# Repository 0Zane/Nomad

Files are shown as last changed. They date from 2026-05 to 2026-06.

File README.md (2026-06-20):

# Nomad

**Outdoor embedded device for exploration**






Nomad is a custom outdoor mobile device built around the **ESP32-S3**. It is designed for explorers, researchers, and outdoor enthusiasts who need reliable positioning, long-range communication, environmental awareness, and practical survival utilities in a compact rugged package.
I made this project entirely myself, the idea comes from my passion of making useful objects that help people in specific actions.

> **Project status:** Active development  
> **Last updated:** June 2026

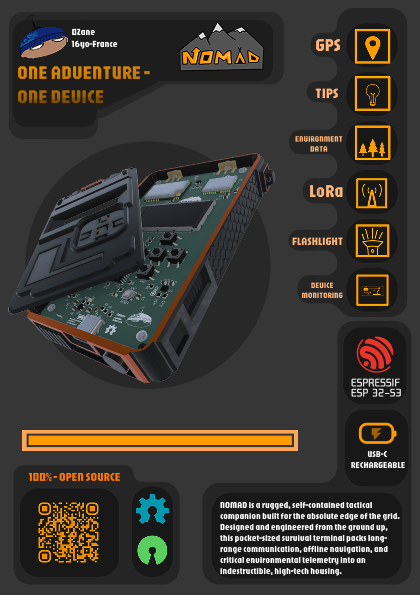
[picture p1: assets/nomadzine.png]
Nomad zine


## Documentation

| Resource | Description |
| --- | --- |
| [Nomad Zine](https://github.com/0Zane/Nomad/blob/341650ad904c9da342a7fef04f9b7398d65ead2c/assets/nomadzine.png) | Visual project zine and product-style overview |
| [Bill of Materials](https://github.com/0Zane/Nomad/blob/main/pcb/bom.csv) | Complete component list with quantities and specifications |
| [Main Schematic](https://github.com/0Zane/Nomad/blob/1c8a336e28e47b4648a542668c6f2eea3e4071de/pcb/nomad.svg) | Full board schematic |
| [Module Schematic](https://github.com/0Zane/Nomad/blob/1c8a336e28e47b4648a542668c6f2eea3e4071de/pcb/modules.svg) | Supporting module schematic |

## Table of Contents

- [Project Overview](#project-overview)
- [Key Features](#key-features)
- [Technical Architecture](#technical-architecture)
- [Hardware Design](#hardware-design)
- [Bill of Materials](#bill-of-materials)
- [Firmware](#firmware)
- [Project Structure](#project-structure)
- [License](#license)

## Project Overview

Nomad combines navigation, messaging, sensing, power management, and a custom interface into one portable embedded system.

The device is built for field use, with an emphasis on:

- Knowing where you are through GPS positioning and waypoint tracking.
- Staying connected through long-range LoRa messaging.
- Understanding local conditions through environmental sensing.
- Conserving energy through deep sleep and power-aware firmware.
- Providing simple, fast interaction through buttons and a menu-driven UI.
- Accessing to useful survival tips 
## Key Features

| Feature | What it enables |
| --- | --- |
| **GPS navigation** | Real-time position, coordinates, and waypoint-oriented navigation |
| **LoRa communication** | Long-range SOS alerts, coordinate sharing, and lightweight messages |
| **Environmental monitoring** | Temperature, pressure, and altitude-related readings |
| **Menu-driven UI** | Multi-level navigation built around a clear state-machine structure |
| **Survival tips** | Practical outdoor guidance available directly on the device |
| **Battery optimization** | Deep sleep and intelligent power-management behavior |
| **Custom PCB** | Purpose-built hardware layout for the full Nomad system |
| **Rugged enclosure** | 3D-designed case for portable outdoor use |

## Technical Architecture

### Core Components

| Component | Specification | Interface | Purpose |
| --- | --- | --- | --- |
| **MCU** | ESP32-S3-WROOM-1U | GPIO, UART, SPI, I2C | Main processor running C++ firmware with PlatformIO and Arduino |
| **Display** | 1.9 in IPS ST7789 display panel via FPC | SPI | Smooth UI rendering with menu/submenu screens and PWM brightness control |
| **GPS** | u-blox NEO-M8M | UART | High-precision localization using the TinyGPS++ library |
| **LoRa** | Ebyte E220-900T22S | UART | Long-range messaging for SOS, coordinate sharing, and text packets |
| **Environmental sensor** | BME280 | I2C | Temperature and atmospheric pressure sensing |
| **Input** | 5 buttons with PCF8574T GPIO expander | I2C | Robust button handling with interrupt support |
| **Fuel gauge** | MAX17048G_T10 | I2C | Battery voltage and state-of-charge monitoring |
| **Charger IC** | MCP73831-2-OT | Power management | Li-Po battery charging management |
| **Buck-boost converter** | TPS63060 | Power management | Stable regulated power delivery |
| **Flashlight** | LED | GPIO pin 1 | Controlled illumination for field use |
| **Power source** | Protected Li-ion battery | Power | Main battery with integrated protection circuit |

### Development Stack

| Layer | Tooling |
| --- | --- |
| **Language** | C++ |
| **Framework** | Arduino |
| **Build system** | PlatformIO |
| **IDE** | VS Code with the PlatformIO extension |
| **Primary firmware target** | ESP32-S3 |

## Hardware Design

### Main Schematic

Nomad main schematic

### Module Schematic

Nomad module schematic

### PCB Layout

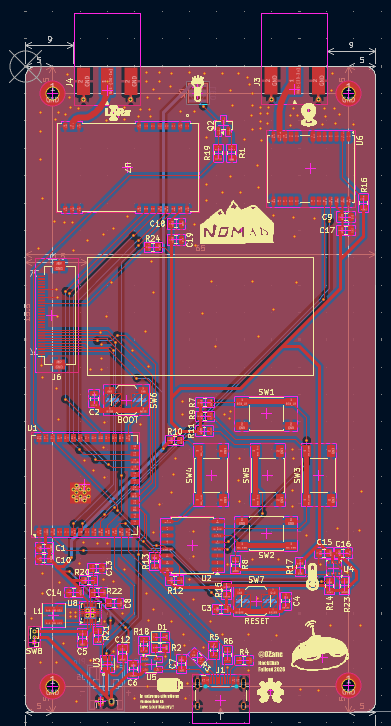
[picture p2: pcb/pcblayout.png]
Nomad PCB layout


### 3D Case

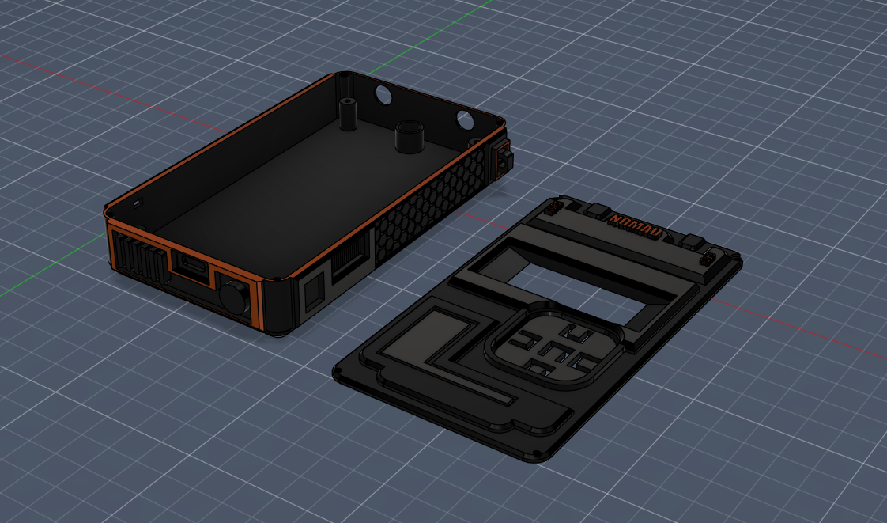
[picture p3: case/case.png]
Nomad case


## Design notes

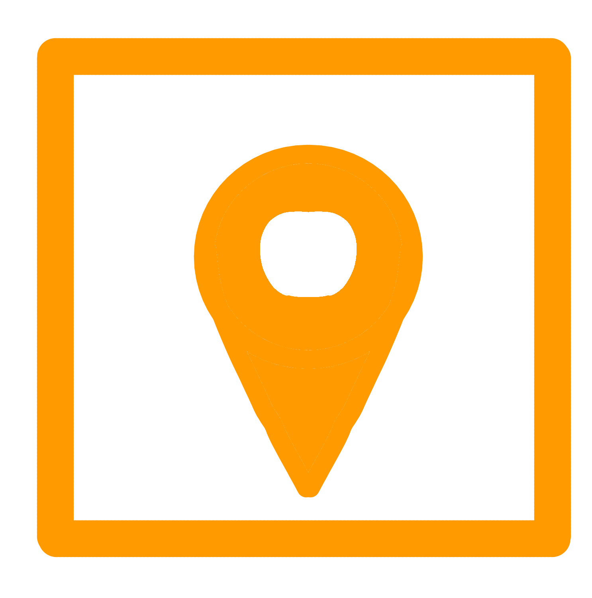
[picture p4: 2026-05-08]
assets/gps.png

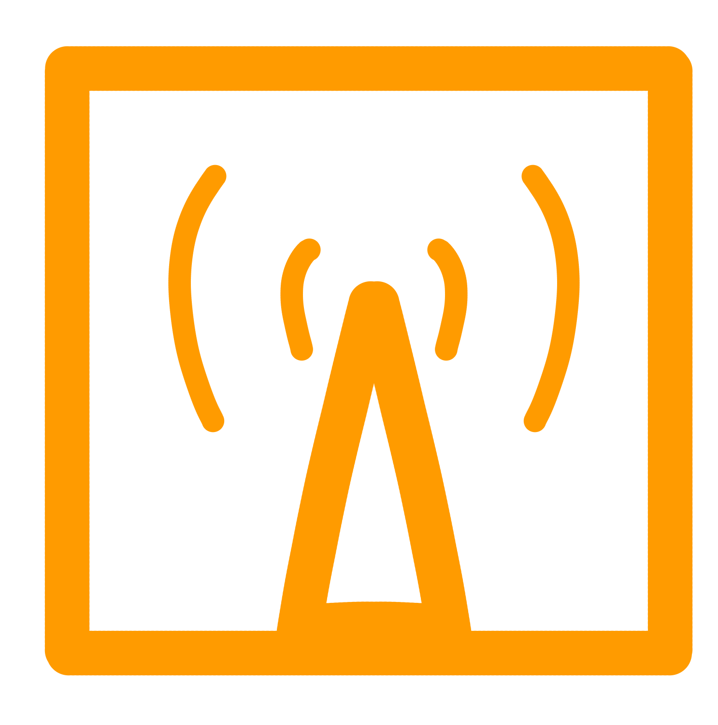
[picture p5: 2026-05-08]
assets/lora.png

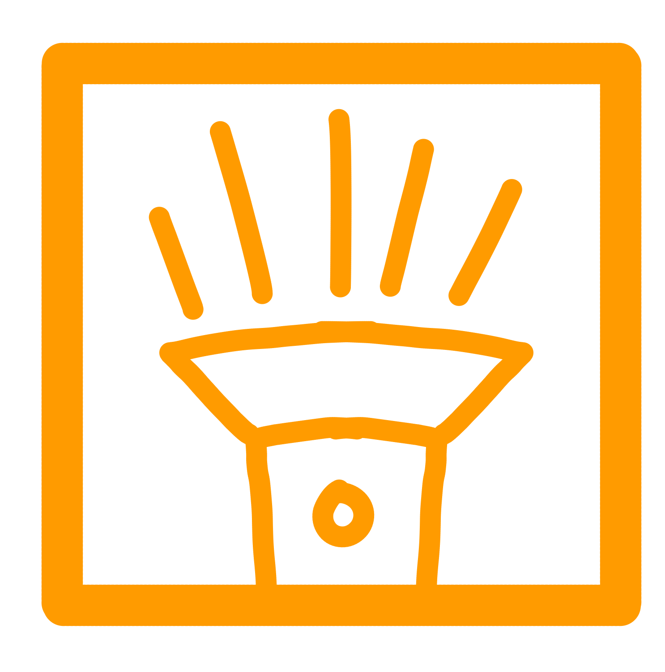
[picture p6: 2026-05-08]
assets/flashlight.png

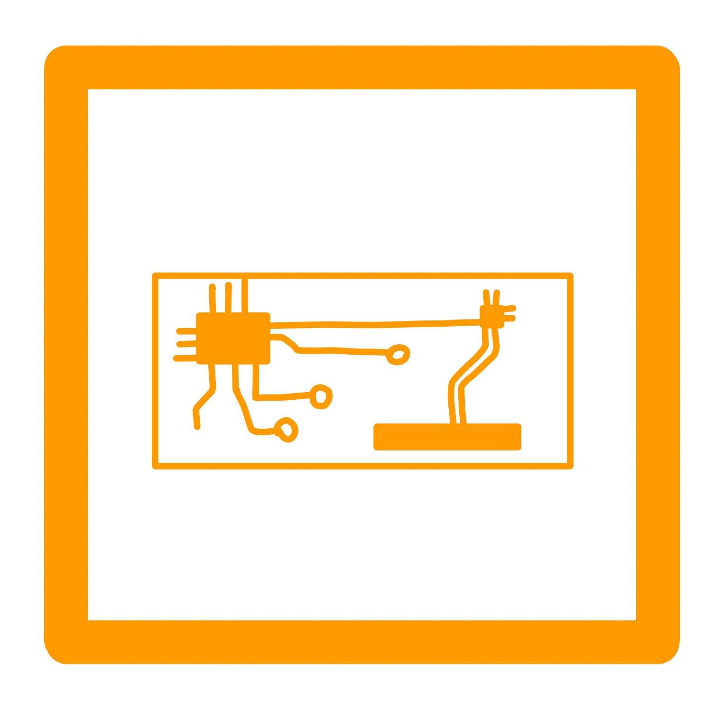
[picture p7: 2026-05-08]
assets/device.png

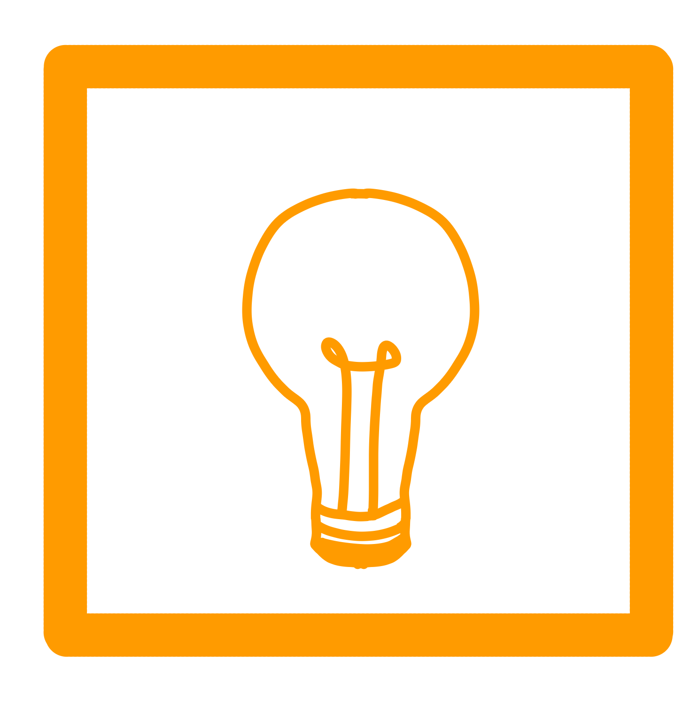
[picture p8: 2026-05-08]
assets/tips.png

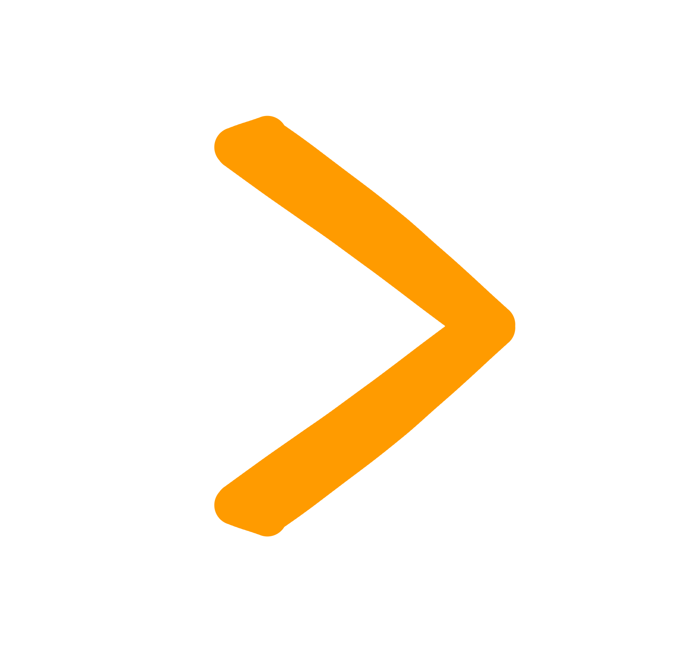
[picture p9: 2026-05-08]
assets/rightarrow.png

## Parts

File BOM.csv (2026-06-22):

Reference | Qty (used) | Value | Footprint | Datasheet | "Ext.price" | "buy link"
C1,C2,C3,C4,C8,C9,C12,C15,C16,C18 | 10 | 0.1uF | Capacitor_SMD:C_0805_2012Metric | "" | $0.25 | "https://www.lcsc.com/product-detail/C1711.html"
C5,C10,C11,C14,C20 | 5 | 22uF | Capacitor_SMD:C_0805_2012Metric | "" | "$0.33" | "https://www.lcsc.com/product-detail/C602037.html"
C6,C7 | 2 | 4.7uF | Capacitor_SMD:C_0805_2012Metric |  | "$0.28" | "https://www.lcsc.com/product-detail/C98192.html"
C13 | 1 | 10pF | Capacitor_SMD:C_0805_2012Metric |  | $0.34 | "https://www.lcsc.com/product-detail/C15850.html"
C17,C19 | 2 | 10uF | Capacitor_SMD:C_0805_2012Metric |  | $0.59 | https://www.lcsc.com/product-detail/C15850.html
D1 | 1 | LED | LED_SMD:LED_0805_2012Metric |  | "1.08€" | "https://fr.aliexpress.com/item/1005006781648580.html"
D2 | 1 | LED | LED_SMD:LED_Cree-XP-G |  | "0.90€" | "https://www.digikey.fr/fr/products/detail/cree-led/XPEBTT-01-0000-00V80/5303634"
J1 | 1 | USB_C_Receptacle_USB2.0_16P | Connector_USB:USB_C_Receptacle_HCTL_HC-TYPE-C-16P-01A | https://www.usb.org/sites/default/files/documents/usb_type-c.zip | "8.99€" | https://www.amazon.fr/dp/B0CJF7KPV8?
J3,J4 | 2 | Conn_Coaxial | Connector_Coaxial:SMA_Molex_73251-1153_EdgeMount_Horizontal |  | "0 | 99€" | "https://fr.aliexpress.com/item/1005009943868026.html"
J5 | 1 | Conn_01x02_Pin | Connector_JST:JST_PH_S2B-PH-K_1x02_P2.00mm_Horizontal |  | "0 | 11 $" | "https://www.digikey.fr/en/products/detail/jst-sales-america-inc/S2B-PH-K-S/926626"
J6 | 1 | Conn_01x30 | Connector_FFC-FPC:Hirose_FH12-30S-0.5SH_1x30-1MP_P0.50mm_Horizontal |  | "2 | 11 $" | "https://www.digikey.fr/en/products/detail/hirose-electric-co-ltd/FH12-30S-0-5SH-55/1000799"
L1 | 1 | 1uH | Inductor_SMD:L_Coilcraft_XxL4020 |  | 1.63€ | https://fr.aliexpress.com/item/1005007108638684.html
Q2 | 1 | 2N7002 | Package_TO_SOT_SMD:SOT-23 | https://www.onsemi.com/pub/Collateral/NDS7002A-D.PDF | "$0.30" | "https://www.lcsc.com/product-detail/C916396.html"
R1 | 1 | 1.5k | Resistor_SMD:R_0805_2012Metric |  | "$0.13" | "https://www.lcsc.com/product-detail/C114555.html"
R2 | 1 | 2K | Resistor_SMD:R_0805_2012Metric |  | "$0.10" | "https://www.lcsc.com/product-detail/C2907248.html"
R3,R4 | 2 | 5.1k | Resistor_SMD:R_0805_2012Metric |  | $0.12 | "https://www.lcsc.com/product-detail/C27834.html"
R5,R6 | 2 | 22R | Resistor_SMD:R_0805_2012Metric |  | $0.10 | "https://www.lcsc.com/product-detail/C2907244.html"
R7,R8,R9,R10,R11,R15,R16 | 7 | 10k | Resistor_SMD:R_0805_2012Metric |  | "$0.10" | "https://www.lcsc.com/product-detail/C2907219.html"
R12,R13,R14,R17 | 4 | 4.7k | Resistor_SMD:R_0805_2012Metric |  | $0.09 | "https://www.lcsc.com/product-detail/C2907326.html"
R18 | 1 | 470R | Resistor_SMD:R_0805_2012Metric |  | "$0.11" | "https://www.lcsc.com/product-detail/C2907267.html"
R19 | 1 | 100R | Resistor_SMD:R_0805_2012Metric |  | "$0.34" | "https://www.lcsc.com/product-detail/C844936.html"
R20 | 1 | 560k | Resistor_SMD:R_0805_2012Metric |  | "$0.09" | "https://www.lcsc.com/product-detail/C2933556.html"
R21 | 1 | 1M | Resistor_SMD:R_0805_2012Metric |  | "4.19€" | "https://fr.aliexpress.com/item/1005005580397963.html"
R22 | 1 | 100k | Resistor_SMD:R_0805_2012Metric |  | "$0.12" | "https://www.lcsc.com/product-detail/C149504.html"
R23 | 1 | 1K | Resistor_SMD:R_0805_2012Metric |  | "$0.10" | "https://www.lcsc.com/product-detail/C2907232.html"
R24 | 1 | 5.1R | Resistor_SMD:R_0805_2012Metric |  | "4.19€" | "https://fr.aliexpress.com/item/1005005580397963.html"
SW1,SW2,SW3,SW4,SW5 | 5 |  | Button_Switch_SMD:SW_Push_1P1T_NO_E-Switch_TL3301NxxxxxG |  | "2 | 49€" | "https://fr.aliexpress.com/item/1005006950491591.html"
SW6,SW7 | 2 | SW_Push | Button_Switch_SMD:SW_SPST_SKQG_WithStem |  | "5.89€" | "https://fr.aliexpress.com/item/1005008865429963.html"
SW8 | 1 | SW_SPDT | Connector_PinHeader_1.00mm:PinHeader_1x03_P1.00mm_Vertical |  | "4 | 87€" | "https://fr.aliexpress.com/item/1005007162182882.html"
U1 | 1 | ESP32-S3-WROOM-1 | RF_Module:ESP32-S3-WROOM-1U | https://www.espressif.com/sites/default/files/documentation/esp32-s3-wroom-1_wroom-1u_datasheet_en.pdf | "6 | 29€" | "https://fr.aliexpress.com/item/1005007001487286.html"
U2 | 1 | PCF8574T | Package_SO:SOIC-16W_7.5x10.3mm_P1.27mm | https://www.nxp.com/docs/en/data-sheet/PCF8574_PCF8574A.pdf | "$0.01" | https://www.lcsc.com/product-detail/C398075.html
U3 | 1 | MAX17048G_T10 | MAX17048G_T10:SON50P200X200X80-9N |  | "$1.58" | https://www.lcsc.com/product-detail/C2682616.html
U4 | 1 | BME280 | Package_LGA:Bosch_LGA-8_2.5x2.5mm_P0.65mm_ClockwisePinNumbering | https://www.bosch-sensortec.com/media/boschsensortec/downloads/datasheets/bst-bme280-ds002.pdf | "$3.86" | https://www.lcsc.com/product-detail/C92489.html
U5 | 1 | MCP73831-2-OT | Package_TO_SOT_SMD:SOT-23-5 | http://ww1.microchip.com/downloads/en/DeviceDoc/20001984g.pdf | "$0.59" | https://www.lcsc.com/product-detail/C424093.html
U6 | 1 | NEO-M8M | RF_GPS:ublox_NEO | https://content.u-blox.com/sites/default/files/NEO-M8-FW3_DataSheet_UBX-15031086.pdf | "$18.41" | "https://www.lcsc.com/product-detail/C5119406.html"
U7 | 1 | E220-900T22S | E220-900T22S_BYT | E220-900T22S | "$3.67" | "https://www.lcsc.com/product-detail/C970285.html"
U8 | 1 | TPS63060 | Package_SON:Texas_S-PWSON-N10_ThermalVias | http://www.ti.com/lit/ds/symlink/tps63060.pdf | "$1.08" | "https://www.lcsc.com/product-detail/C48567.html"
PCB | 5 | 2 Layer, 1.6mm | " default High-spec Options on JLCPCB" | "" | "$7.40" | "https://cart.jlcpcb.com/"
PCB shipping | "1" | "6-9 buisness days" | "EuroPacket" | "" | "$8.50" | "https://cart.jlcpcb.com/"
screen | "1" | "Display panel" | "SPI 1.9 IPS TFT LCD Display Panel 170x320 ST7789" | "https://www.buydisplay.com/download/manual/ER-TFT019-1_Datasheet.pdf" | "$6.39" | "https://www.buydisplay.com/full-viewing-angle-spi-1-9-inch-ips-tft-lcd-display-panel-170x320-st7789"
TOTAL PRICE | "" |  |  |  | 57.20$ + 41.51€ | THE PRICE IS NOT FOR 1 NOMAD DEVICE, MOST OF THE COMPONENTS ARE IN KITS

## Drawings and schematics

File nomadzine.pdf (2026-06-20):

# ONE ADVENTURE -

# ONE DEVICE

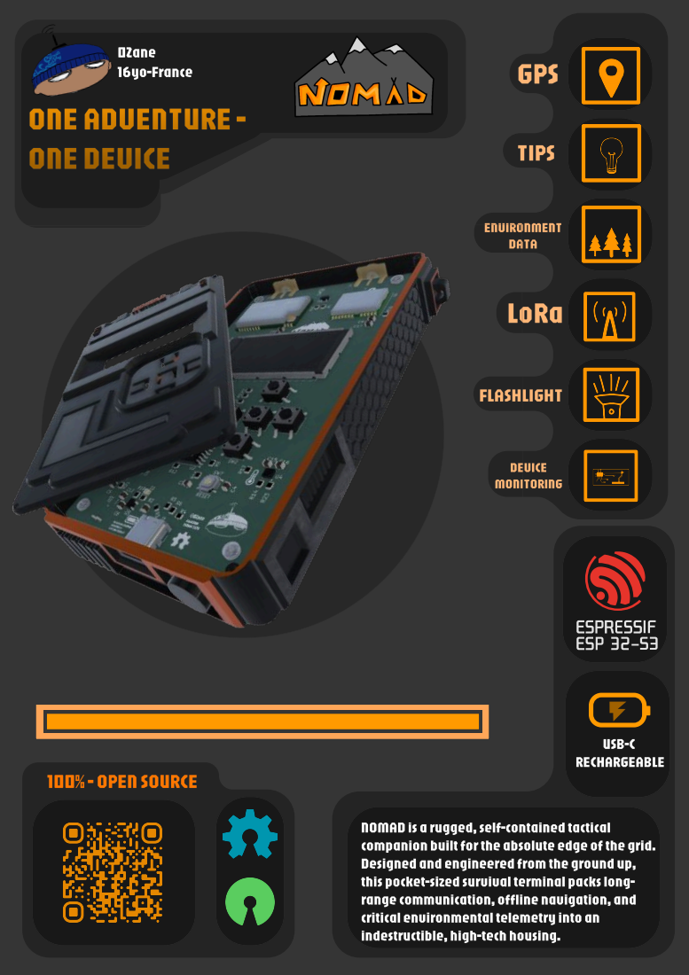
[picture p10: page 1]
0Zane; 16yo-France; GPS; TIPS; ENVIRONMENT; DATA; LoRa; FLASHLIGHT; DEVICE; MONITORING; 100% - OPEN SOURCE; USB-C; RECHARGEABLE

NOMAD is a rugged, self-contained tactical
companion built for the absolute edge of the grid.
Designed and engineered from the ground up,
this pocket-sized survival terminal packs long-
range communication, offline navigation, and
critical environmental telemetry into an
indestructible, high-tech housing.

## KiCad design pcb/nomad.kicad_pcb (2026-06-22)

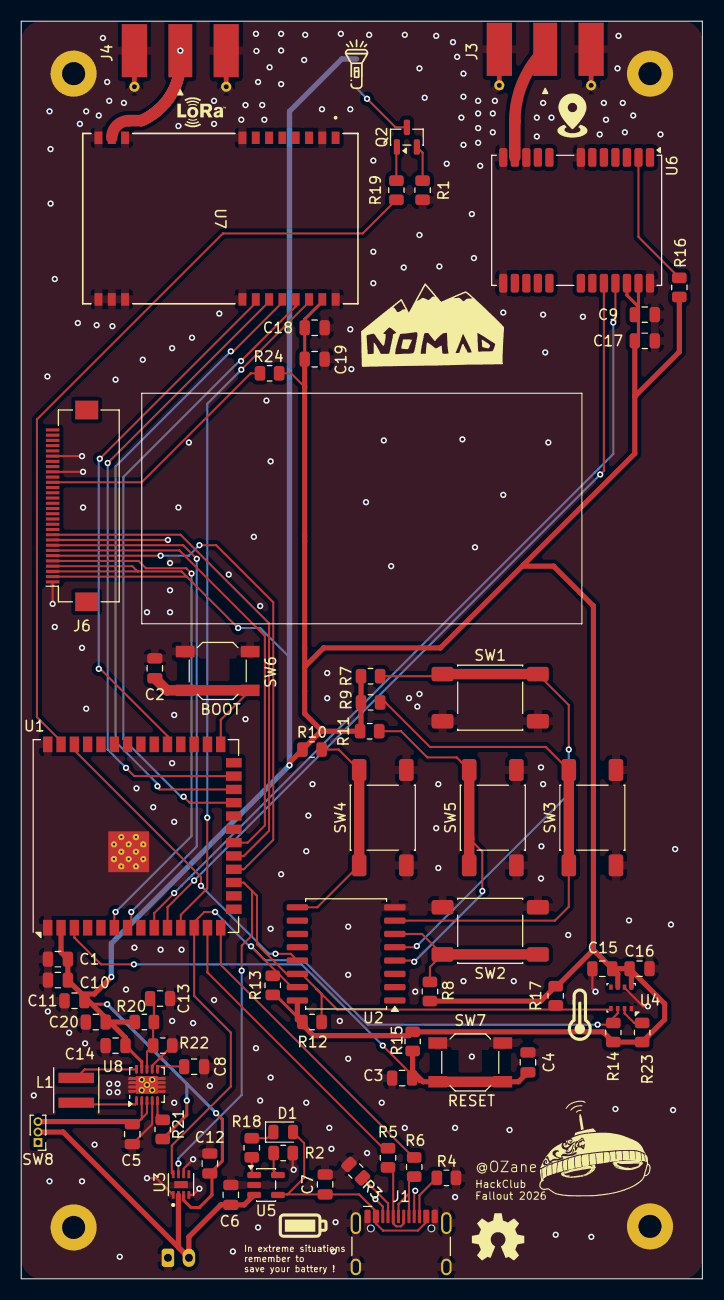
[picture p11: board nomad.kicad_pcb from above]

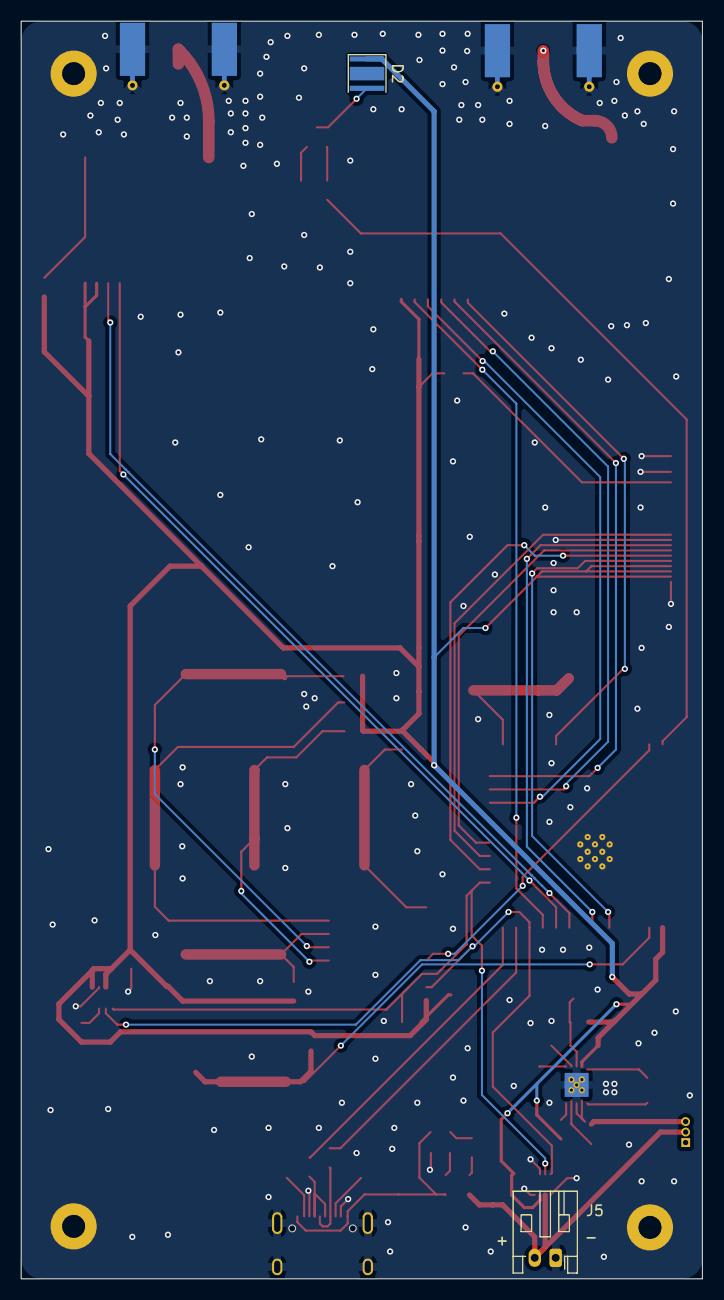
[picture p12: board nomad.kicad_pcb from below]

Board: 2 copper layers, 65.0 x 120.0 mm, 69 parts (2 on the bottom side), 50 nets.

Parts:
C1, C2, C3, C4, C8, C9, C12, C15, C16, C18: 0.1uF; C_0805_2012Metric
C5, C10, C11, C14, C20: 22uF; C_0805_2012Metric
C6: C; C_0805_2012Metric
C7: 4.7uF; C_0805_2012Metric
C13: 10pF; C_0805_2012Metric
C17, C19: 10uF; C_0805_2012Metric
D1: LED; LED_0805_2012Metric
D2: LED; LED_Cree-XP-G
J1: USB_C_Receptacle_USB2.0_16P; USB_C_Receptacle_HCTL_HC-TYPE-C-16P-01A
J3, J4: Conn_Coaxial; SMA_Molex_73251-1153_EdgeMount_Horizontal
J5: Conn_01x02_Pin; JST_PH_S2B-PH-K_1x02_P2.00mm_Horizontal
J6: Conn_01x30; Hirose_FH12-30S-0.5SH_1x30-1MP_P0.50mm_Horizontal
L1: 1uH; L_Coilcraft_XxL4020
Q2: 2N7002; SOT-23
R1: 1.5k; R_0805_2012Metric
R2: 2K; R_0805_2012Metric
R3, R4: 5.1k; R_0805_2012Metric
R5, R6: 22R; R_0805_2012Metric
R7, R8, R9, R10, R11, R16: 10k; R_0805_2012Metric
R12, R13, R14, R17: 4.7k; R_0805_2012Metric
R15: R; R_0805_2012Metric
R18: 470R; R_0805_2012Metric
R19: 100R; R_0805_2012Metric
R20: 560k; R_0805_2012Metric
R21: 1M; R_0805_2012Metric
R22: 100k; R_0805_2012Metric
R23: 1K; R_0805_2012Metric
R24: 4.9R +- 0.2R; R_0805_2012Metric
SW1: UP; SW_Push_1P1T_NO_E-Switch_TL3301NxxxxxG
SW2: DOWN; SW_Push_1P1T_NO_E-Switch_TL3301NxxxxxG
SW3: RIGHT; SW_Push_1P1T_NO_E-Switch_TL3301NxxxxxG
SW4: LEFT; SW_Push_1P1T_NO_E-Switch_TL3301NxxxxxG
SW5: SEL; SW_Push_1P1T_NO_E-Switch_TL3301NxxxxxG
SW6, SW7: SW_Push; SW_SPST_SKQG_WithStem
SW8: SW_SPDT; PinHeader_1x03_P1.00mm_Vertical
U1: ESP32-S3-WROOM-1; ESP32-S3-WROOM-1U
U2: PCF8574T; SOIC-16W_7.5x10.3mm_P1.27mm
U3: MAX17048G_T10; SON50P200X200X80-9N
U4: BME280; Bosch_LGA-8_2.5x2.5mm_P0.65mm_ClockwisePinNumbering
U5: MCP73831-2-OT; SOT-23-5
U6: NEO-M8M; ublox_NEO
U7: E220-900T22S; E220-900T22S_BYT
U8: TPS63060; Texas_S-PWSON-N10_ThermalVias

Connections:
+3V3: C1.1, C9.1, C10.1, C11.1, C12.1, C14.2, C15.1, C16.1, C17.1, C18.2, C19.2, C20.1, D2.1 (K), J6.2, J6.3, J6.4, R7.1, R8.1, R9.1, R10.1, R11.1, R12.1, R13.1, R14.1, R15.1, R16.2, R17.1, R20.2, R21.1, R23.1, R24.1, U1.2 (3V3), U2.16 (VDD), U3.3 (VDD), U4.6 (VDDIO), U4.8 (VDD), U6.22 (V_BCKP), U6.23 (VCC), U7.25 (VCC), U8.9 (VOUT)
+5V: C7.1, D1.2 (A), J1.A4 (VBUS), J1.A9 (VBUS), J1.B4 (VBUS), J1.B9 (VBUS), U5.4 (V_{DD})
+BATT: C6.1, J5.2, SW8.2 (B), U3.2 (CELL), U5.3 (V_{BAT})
AUX: U1.11 (IO18), U7.24 (AUX)
BOOT: C2.1, SW6.1, U1.27 (IO0)
BTN_DOWN: R8.2, SW2.1, U2.6 (P2)
BTN_LEFT: R10.2, SW4.1, U2.9 (P4)
BTN_RIGHT: R9.2, SW3.1, U2.7 (P3)
BTN_SEL: R11.2, SW5.1, U2.4 (P0)
BTN_UP: R7.2, SW1.1, U2.5 (P1)
BUTTON_INT: U1.38 (IO2), U2.13 (~INT)
CS: J6.6, U1.18 (IO10)
DC: J6.8, U1.7 (IO7)
FLASHLIGHT: R19.2, U1.39 (IO1)
GND: C1.2, C2.2, C3.2, C4.2, C5.1, C6.2, C7.2, C8.2, C9.2, C10.2, C11.2, C12.2, C13.1, C14.1, C15.2, C16.2, C17.2, C18.1, C19.1, C20.2, J1.A1 (GND), J1.A8 (SBU1), J1.A12 (GND), J1.B1 (GND), J1.B8 (SBU2), J1.B12 (GND), J1.SH (SHIELD), J3.2 (Ext), J4.2 (Ext), J5.1, J6.1, J6.9, J6.22, J6.25, R1.1, R2.2, R3.1, R4.1, R22.2, SW1.2, SW2.2, SW3.2, SW4.2, SW5.2, SW6.2, SW7.2, U1.1 (GND), U1.40 (GND), U1.41 (GND), U2.8 (GND), U3.1 (CTG), U3.4 (GND), U3.6 (QSTRT), U3.9 (EP), U4.1 (GND), U4.7 (GND), U5.2 (V_{SS}), U6.7 (VDD_USB), U6.10 (GND), U6.12 (GND), U6.13 (GND), U6.24 (GND), U7.2 (GND), U7.8 (GND), U7.11 (GND), U7.13 (GND), U7.14 (GND), U7.15 (GND), U7.16 (GND), U7.19 (GND), U7.26 (GND), U8.4 (PS/SYNC), U8.7 (GND), U8.11 (PGND)
GPS MI: U1.10 (IO17), U6.20 (TXD/SPI_MISO)
GPS MO: U1.9 (IO16), U6.21 (RXD/SPI_MOSI)
LORA_MI: U1.23 (IO21), U7.23 (TXD)
LORA_MO: U1.24 (IO47), U7.22 (RXD)
M0: U1.31 (IO38), U7.20 (M0)
M1: U1.25 (IO48), U7.21 (M1)
MOSI: J6.10, U1.19 (IO11)
unnamed: D1.1 (K), R18.1
unnamed: D2.2 (A), Q2.3 (D)
unnamed: J1.A5 (CC1), R3.2
unnamed: J1.B5 (CC2), R4.2
unnamed: J1.A6 (D+), J1.B6 (D+), R6.1
unnamed: J1.A7 (D-), J1.B7 (D-), R5.1
unnamed: J3.1 (In), U6.11 (RF_IN)
unnamed: J4.1 (In), U7.12 (ANT)
unnamed: J6.20, R24.2
unnamed: Q2.1 (G), R19.1
unnamed: Q2.2 (S), R1.2
unnamed: C5.2, SW8.3 (C), U8.2 (VIN), U8.3 (EN)
unnamed: R23.2, U4.2 (CSB)
unnamed: R2.1, U5.5 (PROG)
unnamed: R18.2, U5.1 (STAT)
unnamed: R16.1, U6.2 (D_SEL)
unnamed: C13.2, R20.1, R22.1, U8.8 (FB)
unnamed: L1.2, U8.1 (L1)
unnamed: L1.1, U8.10 (L2)
unnamed: R21.2, U8.5 (PG)
unnamed: C8.1, U8.6 (VAUX)
RES: J6.5, U1.6 (IO6)
RESET: C3.1, C4.1, R15.2, SW7.1, U1.3 (EN)
SCL: R12.2, R17.2, U1.17 (IO9), U2.14 (SCL), U3.7 (SCL), U4.4 (SCK)
SCLK: J6.7, U1.20 (IO12)
SDA: R13.2, R14.2, U1.12 (IO8), U2.15 (SDA), U3.8 (SDA), U4.3 (SDI)
USB_D+: R6.2, U1.14 (USB_D+)
USB_D-: R5.2, U1.13 (USB_D-)

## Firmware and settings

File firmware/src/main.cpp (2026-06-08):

//System Libraries
#include <Arduino.h>
#include <Wire.h>

//Firmware headers
#include "gps.h"
#include "navigation.h"
#include "pins.h"
#include "getbattery.h"
#include "flashlight.h"
#include "buttonread.h"
#include "config.h"
#include "readtemperature.h"
#include "lora.h"
#include "ui.h"

bool buttonpressed = true;
int current_page = 0;

// I2C Bus recovery function
void recoverI2C() {
    Serial.println("Attempting I2C bus recovery...");
    pinMode(TEMP_SDA, INPUT_PULLUP);
    pinMode(TEMP_SCL, INPUT_PULLUP);
    delay(100);
    for (int i = 0; i < 10; i++) {
        digitalWrite(TEMP_SCL, HIGH);
        delayMicroseconds(5);
        digitalWrite(TEMP_SCL, LOW);
        delayMicroseconds(5);
    }
    pinMode(TEMP_SDA, INPUT);
    pinMode(TEMP_SCL, INPUT);
    delay(100);
    Serial.println("I2C recovery complete");
}

void setup(){

    
    // SERIAL INITIALIZATION - DO THIS FIRST
    Serial.begin(115200);
    Serial1.begin(9600, SERIAL_8N1, LORA_RX, LORA_TX);
    delay(1000); // Wait for Serial to be ready
    Serial.println("\n\n=== Nomad Firmware Starting ===\n");

    //SCREEN INITIALIZATION
    tft.init();
    tft.setRotation(1);
    drawboot();

    // I2C INITIALIZATION (for BME280 and PCF8574)
    Serial.println("Initializing I2C bus...");
    pinMode(TEMP_SDA, INPUT_PULLUP);
    pinMode(TEMP_SCL, INPUT_PULLUP);
    delay(100);
    Wire.begin(TEMP_SDA, TEMP_SCL);
    Wire.setClock(100000);  // Slow clock for reliability
    delay(200);
    Serial.println("I2C Bus initialized at 100kHz");
    
    // GPS INITIALIZATION
    Serial.println("Initializing GPS UART...");
    gpsSerial.begin(GPS_BAUD, SERIAL_8N1, RXD2, TXD2);
    delay(100);
    Serial.println("Serial 2 started at 9600 baud rate");
    
    //LORA MODULE INITIALIZATION
    Serial.println("Initializing EBYTE E22 Lora module...");
    int lora_retries = 3;
    while (!e220ttl.begin() && lora_retries > 0) {
    Serial.print("PCF8574 init failed, retrying... (");
    Serial.print(lora_retries);
    Serial.println(" retries left)");
    e220ttl.begin();
    delay(500);
    lora_retries--;
    }
    
    if (lora_retries == 0) {
        Serial.println("ERROR: Could not initialize Lora EBYTE E22 module after retries!");
    } else {
        Serial.println("lora EBYTE E22 found!");
        Serial.println("testing the module...");
        ResponseStatus rs = e220ttl.sendMessage("Hello, world?");
        // Check If there is some problem of successfully send
        Serial.println(rs.getResponseDescription());
    }
    
    // PCF GPIO EXTENDER INITIALISATION
    Serial.println("Initializing PCF8574 GPIO extender (0x20)...");
    int pcf_retries = 3;
    while (!pcf.begin(0x20, &Wire) && pcf_retries > 0) {
        Serial.print("PCF8574 init failed, retrying... (");
        Serial.print(pcf_retries);
        Serial.println(" retries left)");
        recoverI2C();
        Wire.begin(TEMP_SDA, TEMP_SCL);
        Wire.setClock(100000);
        delay(500);
        pcf_retries--;
    }
    
    if (pcf_retries == 0) {
        Serial.println("ERROR: Could not initialize PCF8574 after retries!");
    } else {
        Serial.println("PCF8574 found!");
        for (uint8_t p=0; p<8; p++) {
            pcf.pinMode(p, INPUT_PULLUP);
        }
        Serial.println("PCF8574 pins configured");
    }
    delay(100);

    //TEMPERATURE SENSOR INITIALISATION
    Serial.println("Initializing BME280 temperature sensor (0x76)...");
    int bme_retries = 3;
    while (!bme.begin(0x76, &Wire) && bme_retries > 0) {
        Serial.print("BME280 init failed, retrying... (");
        Serial.print(bme_retries);
        Serial.println(" retries left)");
        recoverI2C();
        Wire.begin(TEMP_SDA, TEMP_SCL);
        Wire.setClock(100000);
        delay(500);
        bme_retries--;
    }
    
    if (bme_retries == 0) {
        Serial.println("ERROR: Could not initialize BME280 after retries!");
    } else {
        Serial.println("BME280 found!");
    }
    delay(100);
    
    //BATTERY MANAGER INITIALIZATION
    Serial.println("Initializing MAX17048 battery manager...");
    if (!maxlipo.begin()) {
        Serial.println("ERROR: Couldnt find Adafruit MAX17048? Make sure a battery is plugged in!");
    } else {
        Serial.print(F("Found MAX17048 with Chip ID: 0x")); 
        Serial.println(maxlipo.getChipID(), HEX);
    }
    delay(100);
    
    Serial.println("=== Setup Complete ===\n");
}


void loop(){

    // If the GPIO extender INT pin is pressed, we ask to the nav funciton to actualize the current page of the menu
    if (!digitalRead(INT)) {
        current_page = nav(readbutton(),current_page);  
        Serial.println(current_page);
        buttonpressed = true;
    }else{buttonpressed = false;}

    if (current_page == 21){
        updateGPS();
        if (isGPSValid()) {
            double latitude = getLatitude();
            double longitude = getLongitude();
            double speed = getSpeed();
            double altitude = getAltitude();
            uint32_t satellites = getSatellites();
            // Now you can use and store these values
            Serial.print("LAT: "); Serial.println(latitude, 6);
            Serial.print("LONG: "); Serial.println(longitude, 6);
            Serial.print("SPEED (km/h): "); Serial.println(speed);
            Serial.print("ALT (m): "); Serial.println(altitude);
            Serial.print("Satellites: "); Serial.println(satellites);
            Serial.print("Time: "); Serial.println(getDateTime());
        } else {
            Serial.println(">> Waiting for GPS lock (satellite acquisition)...");
        }
    } else if (current_page == 1){

        Serial.print("Temperature = ");
        Serial.print(readTemperature());
        Serial.println(" *C");
        
        Serial.print("Pressure = ");
        Serial.print(readPressure());
        Serial.println(" hPa");
        
        Serial.print("Humidity = ");
        Serial.print(readHumidity());
        Serial.println(" %");
        Serial.println();
    
    }
    else if (current_page == 31){
        send_message("Okay");
    }

    else if (current_page == 41){
        Serial.println("This is a survival advice");
    }

        else if (current_page == 51){
            float cellVoltage = getbattery();
            float cellPercentage = maxlipo.cellPercent();
            Serial.print(F("Batt Voltage: ")); Serial.print(cellVoltage, 3); Serial.println(" V");
            Serial.print(F("Batt Percent: ")); Serial.print(cellPercentage, 1); Serial.println(" %");
            Serial.println();

    }


    


    

    delay(300);
    }

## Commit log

2026-04-23 Adding read temperature feature
2026-04-23 Creating KiCad PCB Project
    [nomad.kicad_pcb, nomad.kicad_sch]
2026-04-23 Adding gitignore for unwanted KiCad files.
2026-04-23 Fixing pcb project's .gitignore & initializing Kicad project
    [nomad.kicad_sch]
2026-04-25 Adding button read features.
2026-04-26 Setting button pinmodes to input
2026-04-26 Placing MCP9808 symbol
    [nomad.kicad_sch]
2026-04-27 Wiring USB-C, MCP9808, PCF8574T
    [nomad.kicad_sch]
2026-04-29 Programming the PCF8574 I2C Button inputs
2026-05-02 Reading INT pin before calling readbutton function
2026-05-03 Replacing temperature sensor schematic + adding INT pin on PCF8574
    [nomad.kicad_sch]
2026-05-05 Replacing MCP9808 by BME280 sensor
2026-05-05 Writing pins.h and updating every file to access to the pins easily + fixing GPS program
    [main.cpp]
2026-05-13 Adding BOOT & RESET buttons + ESP32 symbol
    [nomad.kicad_sch]
2026-05-13 Adding voltage divider AMS1117 & USB to UART converter
    [nomad.kicad_sch]
2026-05-14 Separating modules schematic with system schematic
    [modules.kicad_sch, nomad.kicad_sch]
2026-05-14 Adding elements to their respective location on PCB
    [nomad.kicad_pcb]
2026-05-15 Adding battery management system code
2026-05-16 Adding silkscreen icons
    [nomad.kicad_pcb]
2026-05-16 Updating schematic & pcb & BOM
    [modules.kicad_sch, nomad.kicad_pcb, nomad.kicad_sch]
2026-05-18 Updating PCB
    [modules.kicad_sch, nomad.kicad_pcb, nomad.kicad_sch]
2026-05-19 Updating footprints & shematics + replacing components on PCB
    [nomad.kicad_pcb, nomad.kicad_sch]
2026-05-19 Wiring MAX17048 battery percentage module
    [nomad.kicad_sch]
2026-05-20 Correcting Lora UART communication initialization
2026-05-27 Creating functions that returns each data monitored by the BME280 instead of une function that prints everything in the serial monitor.
2026-06-03 Adding battery management system with MCP73831 chip.
    [nomad.kicad_pcb, nomad.kicad_sch]
2026-06-05 Updating footprints, PCb and schematics.
    [modules.kicad_sch, nomad.kicad_pcb, nomad.kicad_sch]
2026-06-13 Correcting pin conflict
2026-06-13 Updating PCB: Adding Buck boost converter, battery protection and other fixes.
    [modules.kicad_sch, nomad.kicad_pcb, nomad.kicad_sch]
2026-06-14 Updating PCB: Removing battery security and adding slide switch
    [nomad.kicad_pcb, nomad.kicad_sch]
2026-06-15 Adding NEO-M8N module schematic + BME280 schematic
    [modules.kicad_sch]
2026-06-15 Adding LoRa module schematic
    [modules.kicad_sch, nomad.kicad_sch]
2026-06-15 Updating PCB and chainging pin for the LoRa module
    [modules.kicad_sch, nomad.kicad_pcb]
2026-06-16 Finishing schematic and updating PCB
    [modules.kicad_sch, nomad.kicad_pcb, nomad.kicad_sch]
2026-06-16 Routing the PCB
    [nomad.kicad_pcb, nomad.kicad_sch]
2026-06-17 Finishing routing
    [nomad.kicad_pcb, nomad.kicad_sch]
2026-06-17 Adding 50ohms traces
    [nomad.kicad_pcb]
2026-06-17 Finishing PCB
    [nomad.kicad_pcb]
2026-06-17 Updating documentation
    [modules.kicad_sch, nomad.kicad_pcb]
2026-06-17 Adding bill of materials
    [bom.csv]
2026-06-18 Fixing reversed polarity battery connector
    [modules.kicad_sch, nomad.kicad_pcb, nomad.kicad_sch]
2026-06-18 Adding schematic svg
2026-06-18 Exporting STEP file of PCB
    [nomad.kicad_pcb]
2026-06-18 Updating README adding schematics and BOM
2026-06-19 Replacing screen pins by screen FPC connector
    [modules.kicad_sch, nomad.kicad_pcb]
2026-06-20 Updating schematic images
2026-06-20 Adding case 3d models
2026-06-20 Adding BOM
    [bom.csv, modules.kicad_sch]
2026-06-20 Uploading PCB gerber file
    [nomad.kicad_pcb]
2026-06-20 Adding case image
2026-06-20 Uploading pcb layout image to get permalink
2026-06-20 Adding PCB layout image
2026-06-22 Adding assembled project 3d files
2026-06-22 Changing 66uF capacitor to 3* 22uF capacitors
    [bom.csv, nomad.kicad_pcb, nomad.kicad_sch]
2026-06-22 Updating bom and adding BOM with every price
    [BOM.csv, bom.csv, nomad.kicad_sch]
2026-06-22 Fixing display
    [BOM.csv]
2026-06-22 adding " that is breaking the display
    [BOM.csv]
2026-06-22 Fixing csv format
    [BOM.csv]
2026-06-22 Updating csv format
    [BOM.csv]
